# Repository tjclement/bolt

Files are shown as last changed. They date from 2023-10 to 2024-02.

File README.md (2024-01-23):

# A new tool to break stuff! ⚒️

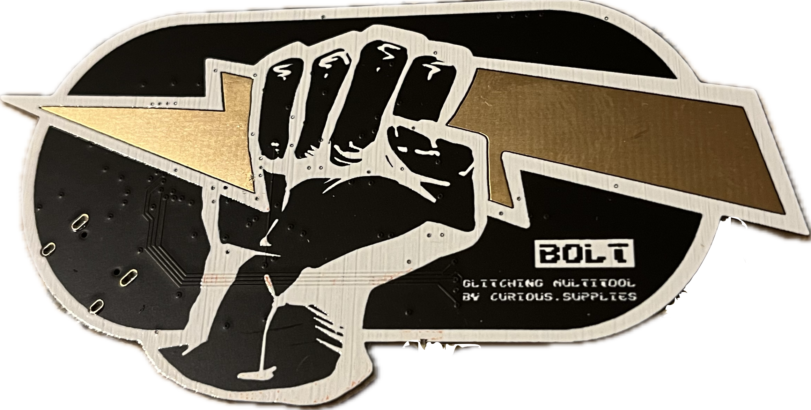
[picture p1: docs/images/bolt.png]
Curious Bolt picture


The Curious Bolt is a security multi-tool for getting started with hardware hacking. It is simultaneously:
- a programmable crowbar **voltage glitcher** ⚡️
- an **8-channel logic analyzer** 👩‍💻
- and a simple differential power analysis **oscilloscope**. 📉

## How do you turn this on?
See [the docs](https://bolt.curious.supplies/docs) for how to set up and use your Bolt.

## Acknowledgements
PulseView scope code by [Jaroslav Kysela](https://github.com/perexg/picoprobe-sump), extended to run in parallel with other functions by Joris Witteman (MIT License)

Software and hardware design by [Joris Witteman](https://github.com/jorisplusplus) for Curious Supplies (MIT License)

PCB art by [ankhaneko.art](https://ankhaneko.art) for Curious Supplies

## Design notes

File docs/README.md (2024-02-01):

For the most recent documentation, check out https://bolt.curious.supplies/docs 👾⚡️

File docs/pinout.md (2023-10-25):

# Curious Bolt pinout
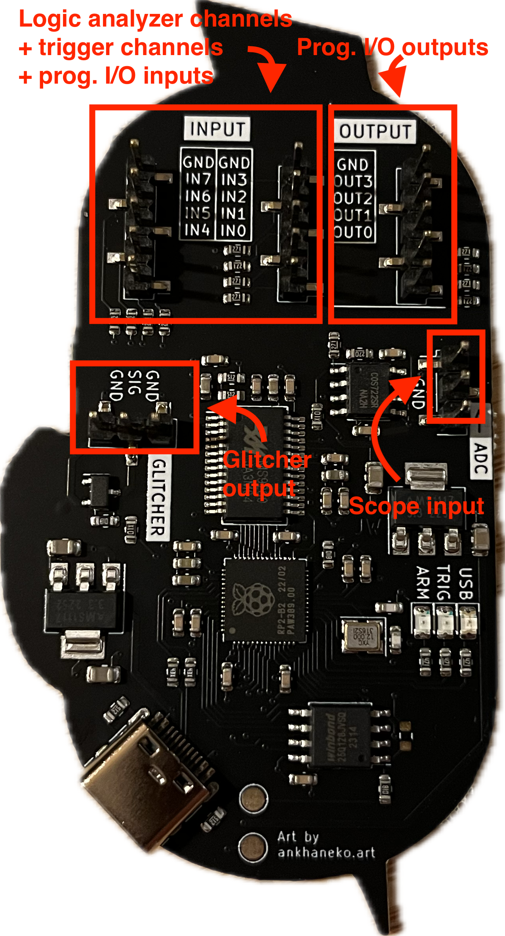
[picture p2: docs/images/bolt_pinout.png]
Curious Bolt pinout


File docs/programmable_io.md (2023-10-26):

# Programmable I/O

You might want to reset your target before glitching, or send a specific sequence of button presses.

The Bolt has 4 output channels that can be programmed to go high or low at certain times after a trigger has occurred (see [Voltage Glitching](voltage_glitching.md#triggering-the-glitch) for info about triggers).

## I/O API

```python
from scope import Scope
s = Scope()

# Set output channel 0 to high level after 500*8.3ns
s.io.add(0, 1, delay=500)

# Set output channel 0 to low level after 1000*8.3ns
s.io.add(0, 0, delay=500)

# Set output channel 3 to high level after 1500*8.3ns
s.io.add(3, 1, delay=1500)

# Write the I/O configs to the device
s.io.upload()

# s.trigger() now triggers the configured I/O sequence

# You can clear I/O configs with s.io.reset()
```

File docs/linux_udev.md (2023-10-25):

# File permissions for USB devices in Linux

Some distros do not allow users access to USB devices by default. If you think this might be the case for you, run the following:

```bash
# Allow access to serial devices
adduser <your username> dialout

# Allow access to other USB devices
adduser <your username> plugdev

# Set SWD debugger to access by plugdev group
echo 'SUBSYSTEM=="usb", ATTRS{idVendor}=="0483", ATTRS{idProduct}=="3748", MODE="0660", GROUP="plugdev"' > /etc/udev/rules.d/49-ecsc.rules

# Now log out and log in again, or run `newgrp -` to load groups only in the current shell
```

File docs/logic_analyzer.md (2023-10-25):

# Using the Curious Bolt as a logic analyzer in PulseView

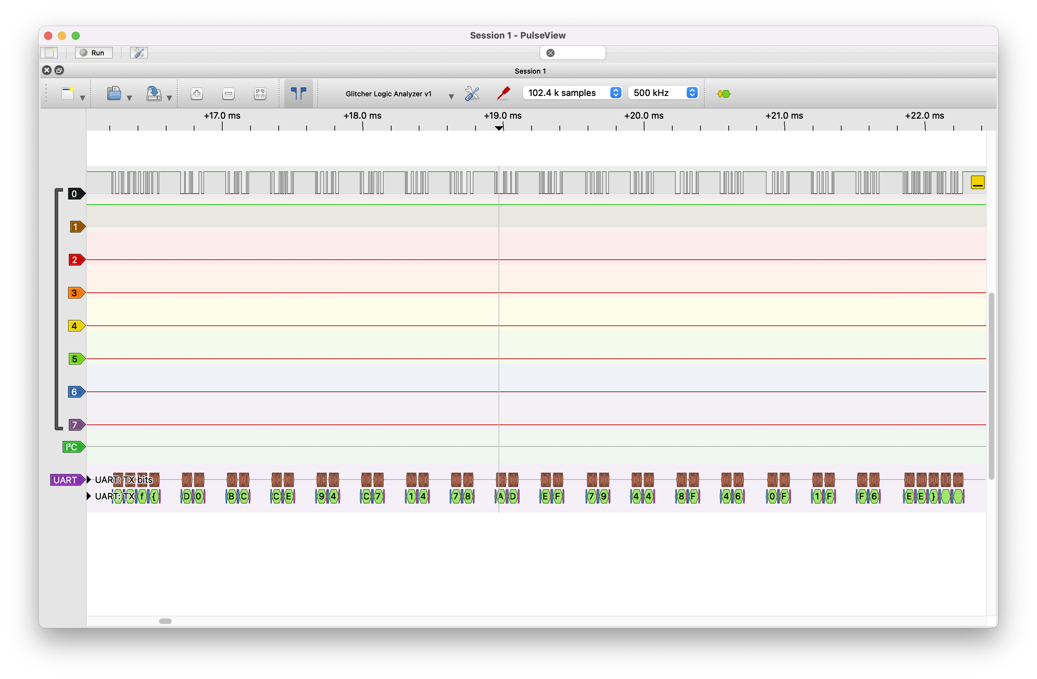
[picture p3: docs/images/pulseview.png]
A screenshot of PulseView being used with Curious Bolt


## How-to
- Install [Pulseview](https://sigrok.org/wiki/Downloads)
- Connect your Curious Bolt via USB
- Open PulseView, and click on "No Device" dropdown
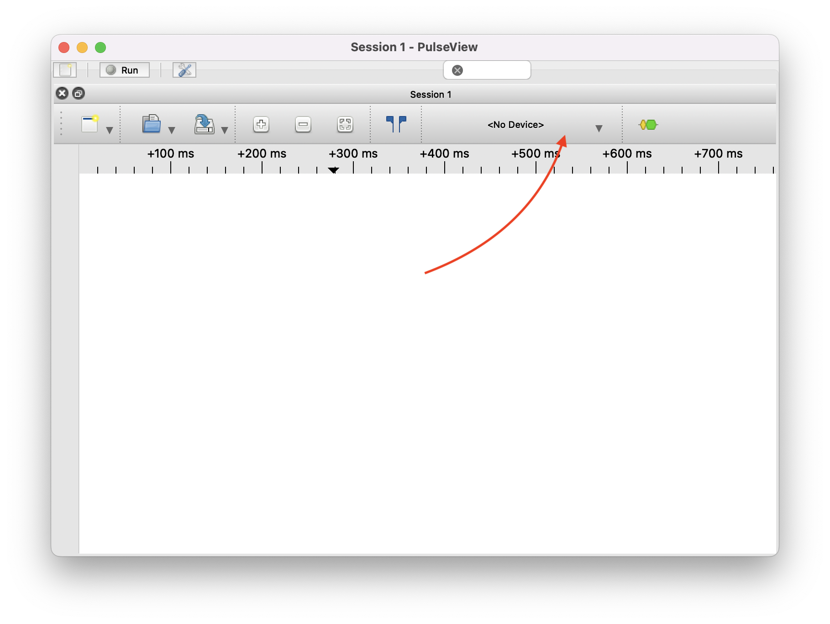
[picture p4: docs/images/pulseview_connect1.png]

- Select the "SUMP Compatibles" driver, select the first USB serial port of the two exposed by Curious Bolt, set the baudrate to 115200, click on Scan, and then Ok
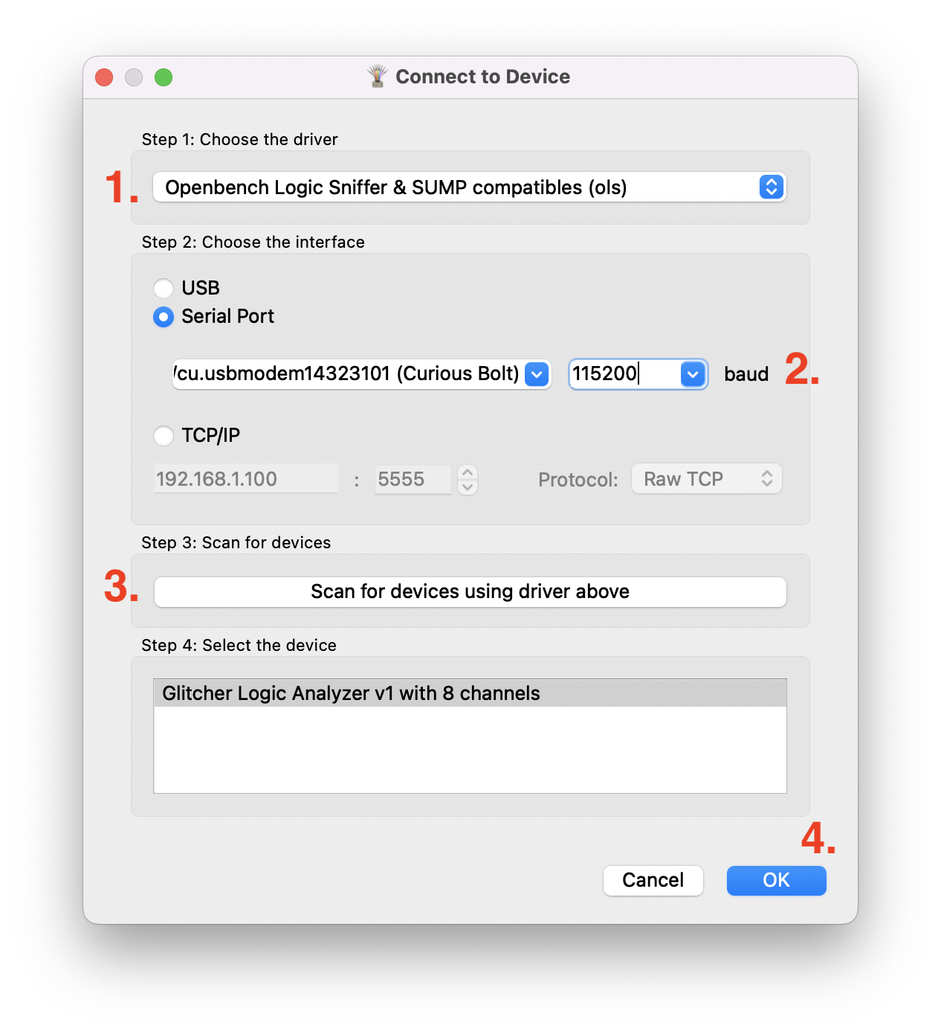
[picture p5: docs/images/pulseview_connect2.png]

- See [Pulseview documentation](https://www.sigrok.org/doc/pulseview/0.4.1/manual.html) for how-to of signal capture and protocol decoding

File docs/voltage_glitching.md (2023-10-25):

# Fault injection using Curious Bolt as a voltage glitcher
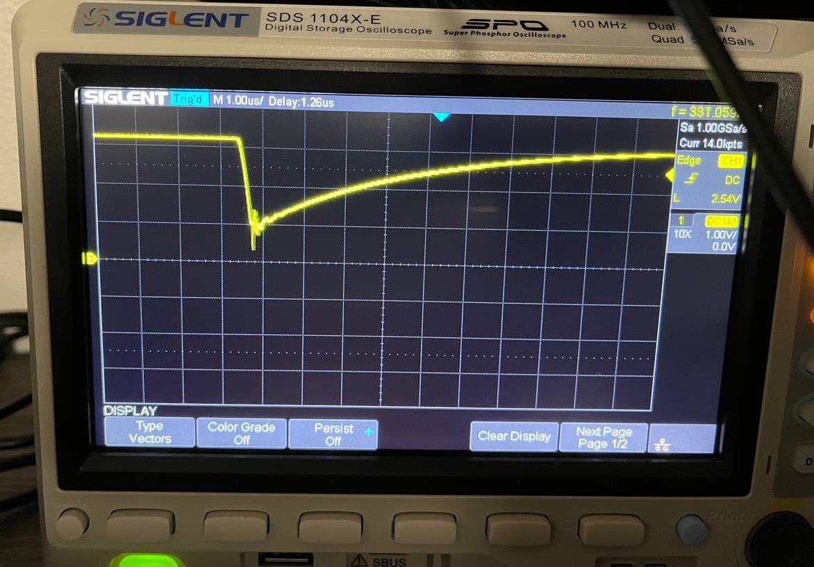
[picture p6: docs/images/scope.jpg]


Curious Bolt has a _crowbar_ voltage glitcher, a type of glitcher that can pull the voltage rails of a target chip to ground at very high resolution (as short as a few nanoseconds).

## Connecting to your target

- Connect at least one wire from ground on the Bolt to ground on the target (see [Pinout](pinout.md)).
- Connect the glitcher _sig_ pin to the voltage rails you want to glitch on your target.

General tip: voltage glitching is finicky and works in very narrow bands. Improve your luck by getting as good a physical connection as you can. Shorter leads, better grounding, and better contact give better results.

## Configuring the glitch

Next you need to configure the duration of your glitch. The python library exposes `Scope.glitch.repeat`, where you can configure how many 8.3ns clock cycles you want the glitch to last:

```python
from scope import Scope
s = Scope()
s.glitch.repeat = 60  # ~0.5 microseconds
```

## Triggering the glitch

Now that you've connected and set up your voltage glitcher, put your target in the state where you want to glitch, and trigger the glitcher once:

```python
s.trigger()
```

This will make the voltage drop very briefly only once. You can also trigger repeatedly, using e.g.:

```python
for i in range(5000):
    s.trigger()
```

Additionally, you can arm the Bolt to be triggered by an incoming signal change on one of the 8 input channels:

```python
# Trigger when input 0 goes from high to low
s.arm(0, Scope.FALLING_EDGE)
```

When triggering from an input pin, you might want to start the glitch some specific time after the trigger occurs. You can set the time offset in 8.3ns cycles before the glitch is executed, using:

```python
s.glitch.ext_offset=1000  # ~8.3 microseconds
```

ℹ️ Note: both manual and external triggers are shared between the glitcher, logic analyzer (via PulseView), and the scope.

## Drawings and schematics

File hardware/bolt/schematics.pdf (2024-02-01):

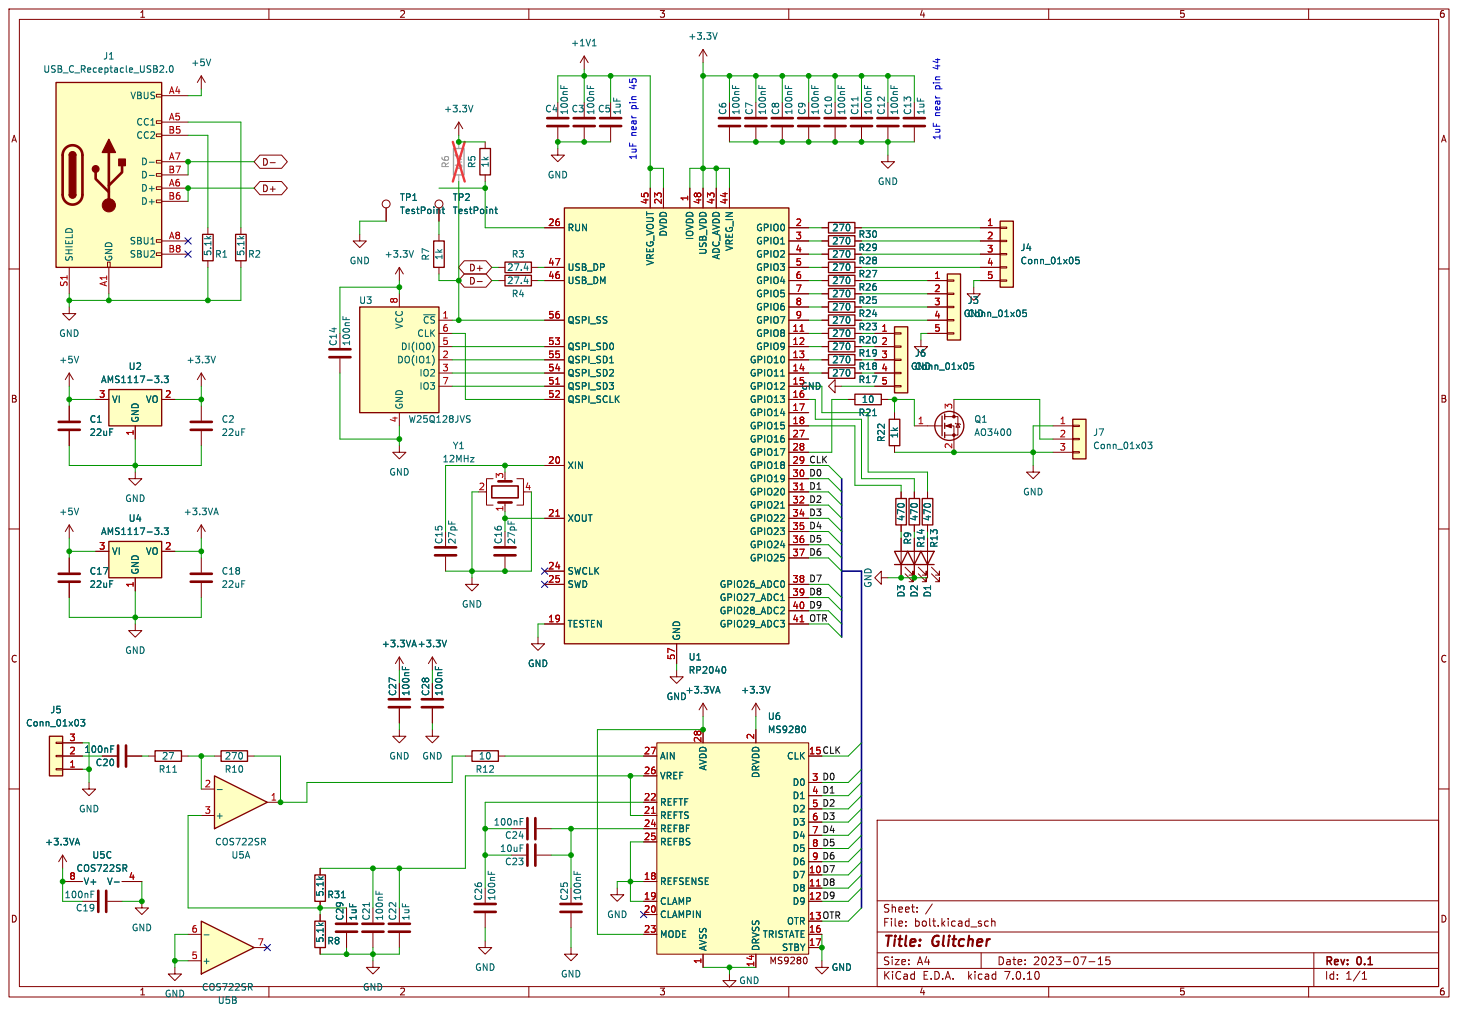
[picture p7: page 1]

Id: 1/1 Title: Glitcher File: bolt.kicad_sch Sheet: /

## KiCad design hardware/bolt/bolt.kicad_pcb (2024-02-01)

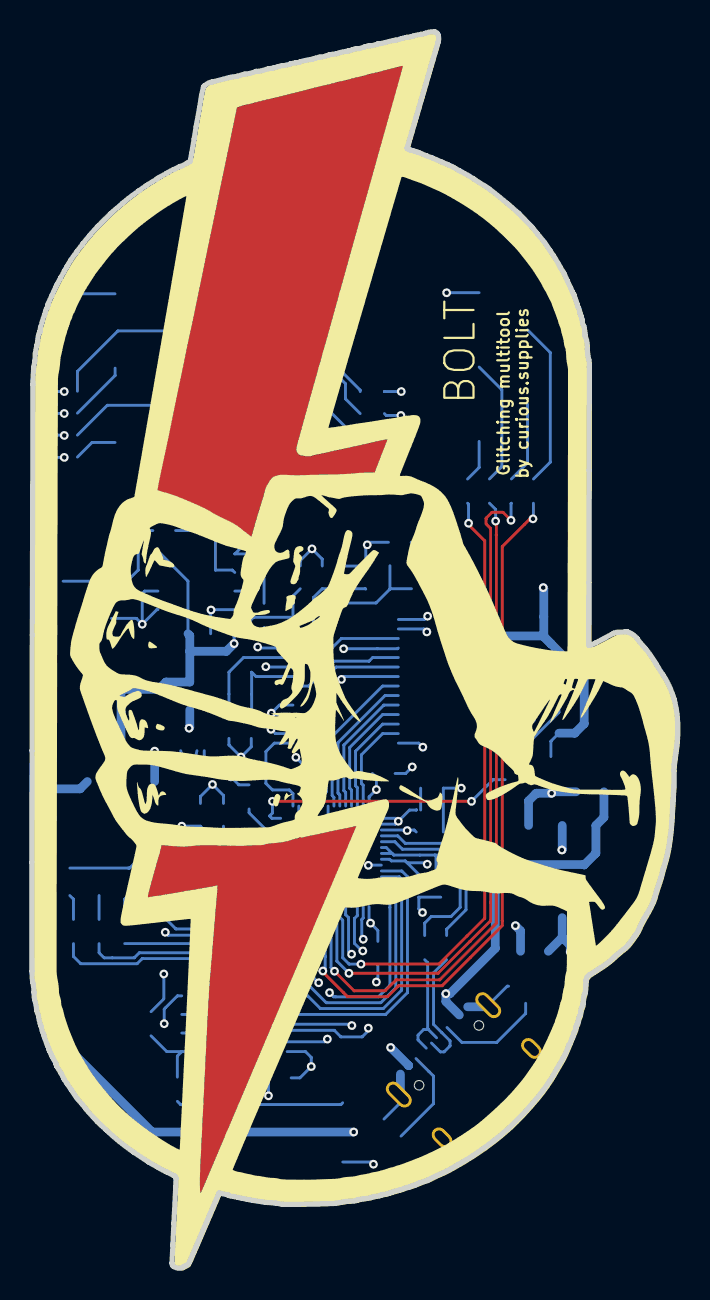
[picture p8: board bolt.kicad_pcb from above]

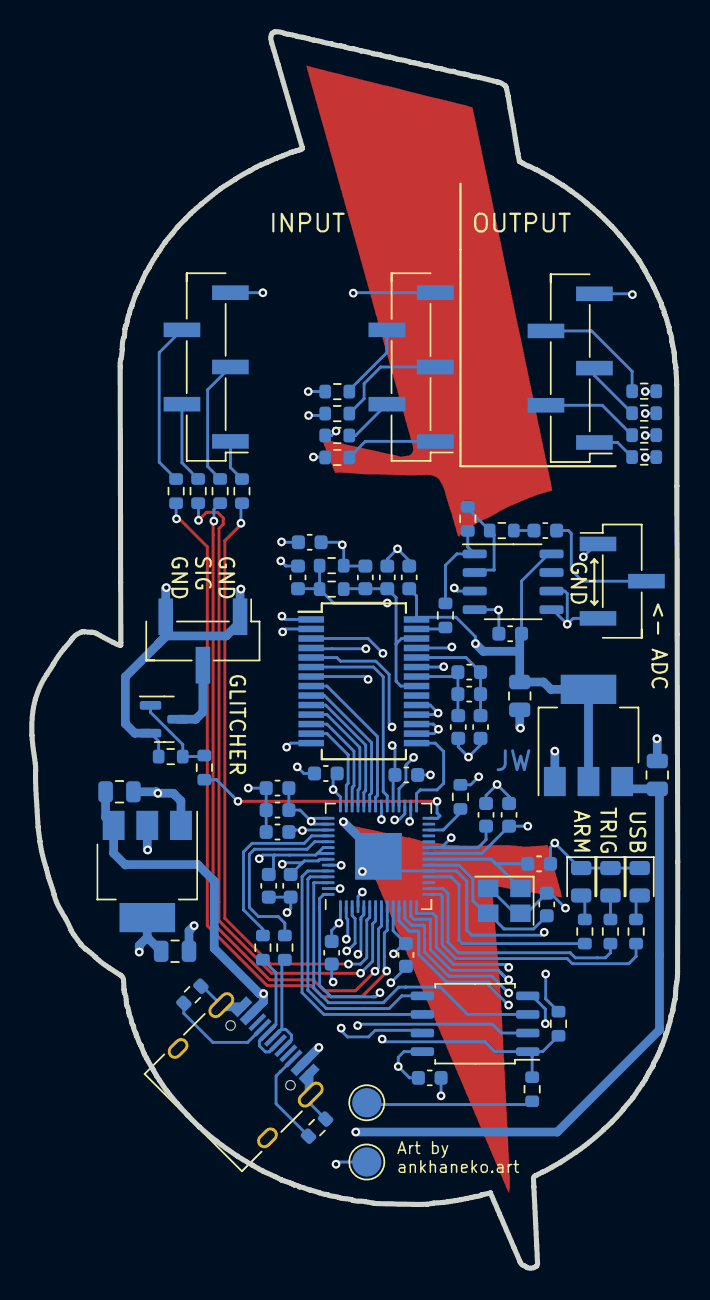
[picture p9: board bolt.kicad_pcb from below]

Board: 4 copper layers, 44.1 x 84.5 mm, 77 parts (77 on the bottom side), 75 nets.

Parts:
C1, C2, C17, C18: 22uF; C_0805_2012Metric
C3, C4, C6, C7, C8, C9, C10, C11, C12, C14, C19, C20, C21, C24, C25, C26, C27, C28: 100nF; C_0603_1608Metric
C5, C13, C22, C29: 1uF; C_0603_1608Metric
C15, C16: 27pF; C_0603_1608Metric
C23: 10uF; C_0603_1608Metric
D1: LED RED; LED_0805_2012Metric
D2, D3: LED YELLOW; LED_0805_2012Metric
J1: USB_C_Receptacle_USB2.0; USB_C_Receptacle_HRO_TYPE-C-31-M-12
J3, J4, J6: Conn_01x05; PinHeader_1x05_P2.54mm_Vertical_SMD_Pin1Left
J5, J7: Conn_01x03; PinHeader_1x03_P2.54mm_Vertical_SMD_Pin1Left
Q1: AO3400; SOT-23
R1, R2, R8, R31: 5.1k; R_0603_1608Metric
R3, R4: 27.4; R_0603_1608Metric
R5, R7, R22: 1k; R_0603_1608Metric
R6: dnf; R_0603_1608Metric
R9, R13, R14: 470; R_0603_1608Metric
R10, R17, R18, R19, R20, R23, R24, R25, R26, R27, R28, R29, R30: 270; R_0603_1608Metric
R11: 27; R_0603_1608Metric
R12, R21: 10; R_0603_1608Metric
TP1, TP2: TestPoint; TestPoint_Pad_D2.0mm
U1: RP2040; QFN-56-1EP_7x7mm_P0.4mm_EP3.2x3.2mm
U2, U4: AMS1117-3.3; SOT-223-3_TabPin2
U3: W25Q128JVS; SOIC-8_5.23x5.23mm_P1.27mm
U5: COS722SR; SOP-8_3.9x4.9mm_P1.27mm
U6: MS9280; SSOP-28_5.3x10.2mm_P0.65mm
Y1: 12MHz; Crystal_SMD_3225-4Pin_3.2x2.5mm

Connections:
+1V1: C3.1, C4.1, C5.1, U1.23 (DVDD), U1.45 (VREG_VOUT), U1.50 (DVDD)
+3.3V: C2.1, C6.1, C7.1, C8.1, C9.1, C10.1, C11.1, C12.1, C13.1, C14.1, C28.1, R5.2, R6.2, U1.1 (IOVDD), U1.10 (IOVDD), U1.22 (IOVDD), U1.33 (IOVDD), U1.42 (IOVDD), U1.43 (ADC_AVDD), U1.44 (VREG_IN), U1.48 (USB_VDD), U1.49 (IOVDD), U2.2 (VO), U3.8 (VCC), U6.2 (DRVDD)
+3.3VA: C18.1, C19.1, C27.1, U4.2 (VO), U5.8 (V+), U6.23 (MODE), U6.28 (AVDD)
+5V: C1.1, C17.1, J1.A4 (VBUS), J1.A9 (VBUS), J1.B4 (VBUS), J1.B9 (VBUS), U2.3 (VI), U4.3 (VI)
/CLK: U1.29 (GPIO18), U6.15 (CLK)
/D0: U1.30 (GPIO19), U6.3 (D0)
/D1: U1.31 (GPIO20), U6.4 (D1)
/D2: U1.32 (GPIO21), U6.5 (D2)
/D3: U1.34 (GPIO22), U6.6 (D3)
/D4: U1.35 (GPIO23), U6.7 (D4)
/D5: U1.36 (GPIO24), U6.8 (D5)
/D6: U1.37 (GPIO25), U6.9 (D6)
/D7: U1.38 (GPIO26_ADC0), U6.10 (D7)
/D8: U1.39 (GPIO27_ADC1), U6.11 (D8)
/D9: U1.40 (GPIO28_ADC2), U6.12 (D9)
/OTR: U1.41 (GPIO29_ADC3), U6.13 (OTR)
D+: J1.A6 (D+), J1.B6 (D+), R3.1
D-: J1.A7 (D-), J1.B7 (D-), R4.1
GND: C1.2, C2.2, C3.2, C4.2, C5.2, C6.2, C7.2, C8.2, C9.2, C10.2, C11.2, C12.2, C13.2, C14.2, C15.2, C16.2, C17.2, C18.2, C19.2, C21.2, C22.2, C25.2, C26.2, C27.2, C28.2, C29.2, D1.1 (K), D2.1 (K), D3.1 (K), J1.A1 (GND), J1.A12 (GND), J1.B1 (GND), J1.B12 (GND), J1.S1 (SHIELD), J3.5, J4.5, J5.1, J5.3, J6.5, J7.1, J7.3, Q1.2 (S), R1.1, R2.1, R8.1, R22.1, TP1.1, U1.19 (TESTEN), U1.57 (GND), U2.1 (GND), U3.4 (GND), U4.1 (GND), U5.4 (V-), U5.5 (+), U5.6 (-), U6.1 (AVSS), U6.14 (DRVSS), U6.16 (TRISTATE), U6.17 (STBY), U6.18 (REFSENSE), U6.19 (CLAMP), U6.25 (REFBS), Y1.2, Y1.4
unnamed: C20.2, R11.2
unnamed: D1.2 (A), R13.1
unnamed: D2.2 (A), R14.1
unnamed: D3.2 (A), R9.1
unnamed: J1.A5 (CC1), R2.2
unnamed: J1.B5 (CC2), R1.2
unnamed: J3.1, R26.1
unnamed: J3.2, R25.1
unnamed: J3.3, R24.1
unnamed: J3.4, R23.1
unnamed: J4.1, R30.1
unnamed: J4.2, R29.1
unnamed: J4.3, R28.1
unnamed: J4.4, R27.1
unnamed: C20.1, J5.2
unnamed: J6.1, R20.1
unnamed: J6.2, R19.1
unnamed: J6.3, R18.1
unnamed: J6.4, R17.1
unnamed: J7.2, Q1.3 (D)
unnamed: Q1.1 (G), R21.1, R22.2
unnamed: R7.2, TP2.1
unnamed: R10.1, R12.2, U5.1
unnamed: R30.2, U1.2 (GPIO0)
unnamed: R29.2, U1.3 (GPIO1)
unnamed: R28.2, U1.4 (GPIO2)
unnamed: R27.2, U1.5 (GPIO3)
unnamed: R26.2, U1.6 (GPIO4)
unnamed: R25.2, U1.7 (GPIO5)
unnamed: R24.2, U1.8 (GPIO6)
unnamed: R23.2, U1.9 (GPIO7)
unnamed: R20.2, U1.11 (GPIO8)
unnamed: R19.2, U1.12 (GPIO9)
unnamed: R18.2, U1.13 (GPIO10)
unnamed: R17.2, U1.14 (GPIO11)
unnamed: R13.2, U1.15 (GPIO12)
unnamed: R14.2, U1.16 (GPIO13)
unnamed: R9.2, U1.18 (GPIO15)
unnamed: R21.2, U1.28 (GPIO17)
unnamed: U1.52 (QSPI_SCLK), U3.6 (CLK)
unnamed: U1.53 (QSPI_SD0), U3.5 (DI(IO0))
unnamed: U1.55 (QSPI_SD1), U3.2 (DO(IO1))
unnamed: U1.54 (QSPI_SD2), U3.3 (IO2)
unnamed: U1.51 (QSPI_SD3), U3.7 (IO3)
unnamed: R6.1, R7.1, U1.56 (QSPI_SS), U3.1 (~CS)
unnamed: R5.1, U1.26 (RUN)
unnamed: R4.2, U1.46 (USB_DM)
unnamed: R3.2, U1.47 (USB_DP)
unnamed: C15.1, U1.20 (XIN), Y1.3
unnamed: C16.1, U1.21 (XOUT), Y1.1
unnamed: C29.1, R8.2, R31.1, U5.3 (+)
unnamed: R10.2, R11.1, U5.2 (-)
unnamed: R12.1, U6.27 (AIN)
unnamed: C23.2, C24.2, C25.1, U6.24 (REFBF)
unnamed: C23.1, C24.1, C26.1, U6.22 (REFTF)
unnamed: C21.1, C22.1, R31.2, U6.21 (REFTS), U6.26 (VREF)

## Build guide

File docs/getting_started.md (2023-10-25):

# Getting started

## Setting up your Bolt
The Curious Bolt exposes a serial port over USB that can be used to interface with its glitcher, scope, and programmable I/O.

A python library is available to talk to your Bolt. To use it:

- Install _python_ (3.x) and _pip_
- Install _pyserial_ by running `pip install pyserial`
- Copy [scope.py](../lib/scope.py) to your working directory
- Check if you can connect by running `python3 -c "from scope import Scope;s=Scope()"`. If you get a warning that the Bolt could not be found, check its USB connection.
- If you run Linux and can't connect, check [your udev rules](linux_udev.md).

## Logic analysis in PulseView
A screenshot of PulseView being used with Curious Bolt
See [Logic Analyzer](logic_analyzer.md) for instructions.

## Fault injection with the voltage glitcher

See [Voltage Glitching](voltage_glitching.md) for instructions.

## Programmable I/O
You can get the Bolt to send programmable output patterns on its output GPIO, based on triggers. See [Programmable I/O](programmable_io.md).

## Differential power analysis with the oscilloscope
Documentation for this is in progress.

⚠️ **NOTE FOR ECSC23 PARTICIPANTS**: the scope of your Bolt is not necessary for your challenges, and it will not help you either. For the competition you can ignore this feature.

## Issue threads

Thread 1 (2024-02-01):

Bolt up-to-date official Firmware?

wisec, 2024-02-01:
Hey Tom!
congrats for the project!
I am having a lot of fun :)
It would be nice to have an up-to-date bolt firmware source code as I would like to play a bit with it.
I see there's https://github.com/tjclement/ecsc23-badge/tree/main/fw/glitcher but I'm not sure it's the same firmware that's deployed on Bolt release.

Thanks!

tjclement, 2024-02-01:
Hi @wisec, thanks for your kind words! Awesome to hear you like your Bolt.

Totally, bringing the latest fw in on this repo has been on the todo list for a few weeks now. I'll include it as-is for now to get you started, and hope to write some compilation and flashing instructions soon.

For your info now: you can get the Bolt in UF2 fw update mode either by calling Scope.update() from the python API, or by shorting the two round testpoint pads next to the USB connector during power-up.

Cheers!

tjclement, 2024-02-01:
Just checked, and the main branch in the ecsc23 repo is up to date with the firmware flashed on Bolts before shipping. I've also added that codebase to this repo, where development will continue: https://github.com/tjclement/bolt/tree/main/firmware/bolt

Please let me know if you run into anything!

wisec, 2024-02-01:
Super, thanks:)!

I was seeing the BOOTLOADER command missing but I can see it now on bolt repo.
Thanks & keep up!

tjclement, 2024-02-01:
Ah, sharp comment! It turns out that the bootloader command commit had only been pushed to a private origin instead of the public ecsc23 repo. That's fixed now too. Thanks 👍

Closed 2024-02-01.

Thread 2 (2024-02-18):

Link to pinout is broken on Voltage Glitcher page

kxynos, 2024-02-18:
Link to Pinout on https://bolt.curious.supplies/docs/getting-started/voltage_glitching/ is broken.

tjclement, 2024-02-18:
Fixed, thanks for reporting!

Closed 2024-02-18.

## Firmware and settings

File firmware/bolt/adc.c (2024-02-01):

#include <pico/stdlib.h>
#include "hardware/clocks.h"
#include "hardware/irq.h"
#include "hardware/pio.h"
#include "hardware/dma.h"
#include "hardware/pwm.h"
#include "hardware/structs/bus_ctrl.h"
#include "adc.h"

#define DMA_CHANNEL (8)

static int adc_pio_prog_offset;
static uint32_t delay = 10;
static uint16_t buf[ADC_SAMPLES];

static void init_gpio_adc() {
  gpio_init(ADC_CLK);
  pio_gpio_init(ADC_PIO, ADC_CLK);
  
  for (int i = 0; i < 10; i++) {
    gpio_init(ADC_D0+i);
    gpio_set_dir(ADC_D0, GPIO_IN);
  }
}

static void adc_pio_program(void) {
    uint16_t prog[] = {
        pio_encode_pull(false, true),
        pio_encode_mov(pio_x, pio_osr),
        pio_encode_jmp_x_dec(2),
        pio_encode_set(pio_pins, 1),
        pio_encode_in(pio_pins, 10),
        pio_encode_set(pio_pins, 0),
        pio_encode_jmp(3)
    };
    struct pio_program program = {
        .instructions = prog,
        .length = count_of(prog),
        .origin = -1};
    adc_pio_prog_offset = pio_add_program(ADC_PIO, &program);
}

static void adc_dma_program(void) {
    dma_channel_config cfg = dma_channel_get_default_config(DMA_CHANNEL);
    channel_config_set_read_increment(&cfg, false);
    channel_config_set_write_increment(&cfg, true);
    channel_config_set_dreq(&cfg, pio_get_dreq(ADC_PIO, ADC_PIO_SM, false));
    channel_config_set_transfer_data_size(&cfg, DMA_SIZE_16);
    dma_channel_configure(DMA_CHANNEL, &cfg,
                          buf,
                          &ADC_PIO->rxf[ADC_PIO_SM],
                          ADC_SAMPLES,
                          false);
}

void adc_pio_init(void) {
  pio_sm_config c;
  pio_claim_sm_mask(ADC_PIO, 1u << ADC_PIO_SM);
  adc_pio_program();
  init_gpio_adc();
  // loop the IN instruction forewer (8-bit and 16-bit version)
  c = pio_get_default_sm_config();
  sm_config_set_set_pins(&c, ADC_CLK, 1);
  sm_config_set_in_pins(&c, ADC_D0);
  //sm_config_set_wrap(&c, adc_pio_prog_offset, adc_pio_prog_offset+3);
  sm_config_set_clkdiv_int_frac(&c, 1, 64); //100MHz
  sm_config_set_in_shift(&c, false, true, 10);
  pio_sm_set_consecutive_pindirs(ADC_PIO, ADC_PIO_SM, ADC_CLK, 1, true);

  pio_sm_init(ADC_PIO, ADC_PIO_SM, adc_pio_prog_offset, &c);
  pio_sm_set_enabled(ADC_PIO, ADC_PIO_SM, false);
  adc_dma_program();
}

void adc_pio_delay(uint32_t delayns) {
  delay = delayns;
}

void adc_pio_start() {
  pio_sm_set_enabled(ADC_PIO, ADC_PIO_SM, false);
  dma_channel_abort(DMA_CHANNEL);
  pio_sm_clear_fifos(ADC_PIO, ADC_PIO_SM);
  pio_sm_put(ADC_PIO, ADC_PIO_SM, delay);
  pio_sm_exec(ADC_PIO, ADC_PIO_SM, pio_encode_jmp(adc_pio_prog_offset));
  pio_sm_set_enabled(ADC_PIO, ADC_PIO_SM, true);
  dma_channel_set_write_addr(DMA_CHANNEL, buf, true);
}

void adc_config_clkdiv(uint16_t integer, uint16_t frac) {
  pio_sm_set_clkdiv_int_frac(ADC_PIO, ADC_PIO_SM, integer, frac);
}

uint16_t* adc_data() {
  if (dma_channel_is_busy(DMA_CHANNEL)) {
    return NULL;
  }
  return buf;
}

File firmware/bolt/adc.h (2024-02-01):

#ifndef __ADC_H__
#define __ADC_H__

#define ADC_PIO pio1
#define ADC_PIO_SM 1u
#define ADC_CLK (18)
#define ADC_D0 (19)
#define ADC_SAMPLES (50000)

void adc_pio_init(void);
void adc_pio_delay(uint32_t delayns);
uint16_t* adc_data();
void adc_pio_start();
void adc_config_clkdiv(uint16_t integer, uint16_t frac);

#endif

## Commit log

2024-01-08 Added scope data plotting, added bootloader reboot command for updating firmware, made get_last_trace() return floats in Volt by default
2024-02-01 Added gold release Bolt firmware
2024-02-01 Added Bolt hardware design
    [bolt.kicad_pcb, bolt.kicad_sch]
